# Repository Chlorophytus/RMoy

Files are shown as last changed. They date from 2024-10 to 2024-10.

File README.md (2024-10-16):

# RMoy
Simple 12V 0.5A headphone amplifier convergent with the CMoy's design and philosophy. This is in early alpha stage but will be on Tindie soon.

## Background
Initially named "Seven Wonder", I realized that this converged with the famous CMoy headphone amplifier, freely available. I decided to open source it for others to enjoy.

## Specifications
- Gain is about 8x
- OPA2134 opamp (in the process of testing other opamps out there but this seems to be most happy)
- Nichicon UKA capacitors in the signal path (needed for coupling)
- The same magenta LED used in the BD139 Thing

## Caveats
- No knob like the CMoy has, computers and other devices have digital OS volume control. Use those.

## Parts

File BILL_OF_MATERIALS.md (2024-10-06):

# Bill of Materials

You should populate U1 with a Burr Brown/Texas Instruments OPA2134PA.

It is recommended to use a 12V 500mA center-positive power adapter.

## Capacitors

- `C1`/`C2`: Nichicon UKA1H101MPD - 100µF op-amp input coupling
- `C3`/`C4`: Murata RDE5C1H102J0K1H03B - 1nF op-amp pole splitting
- `C5`/`C6`: Nichicon UKA1V221MPD - 220µF op-amp output coupling
- `C7`: Chemi-Con EKZN250ELL471MJC5S - 470µF power coupling
- `C8`: Murata RDE5C1H104J2K1H03B - 100nF power coupling

## Resistors

- `R1`/`R2` - YAGEO MFR-25FBF52-270R - path for audio input to ground
- `R3`/`R4` - YAGEO MFR-25FBF52-100R - path for feedback to ground
- `R5`/`R6` - YAGEO MFR-25FBF52-680R - path for feedback to U1
- `R7` - YAGEO MFR-25FBF52-4K7 - LED current limiting resistor

## Miscellaneous Components

- `J1`/`J2` - Same Sky SJ1-3535 - stereo headphones in/out jacks
- `J3` - Same Sky PJ-102AH - DC power jack
- `U1` - TE Connectivity 2485264-1 - 8-DIP socket for op-amp
- `D1` - Kingbright WP7113VRVC1C - LED power indicator

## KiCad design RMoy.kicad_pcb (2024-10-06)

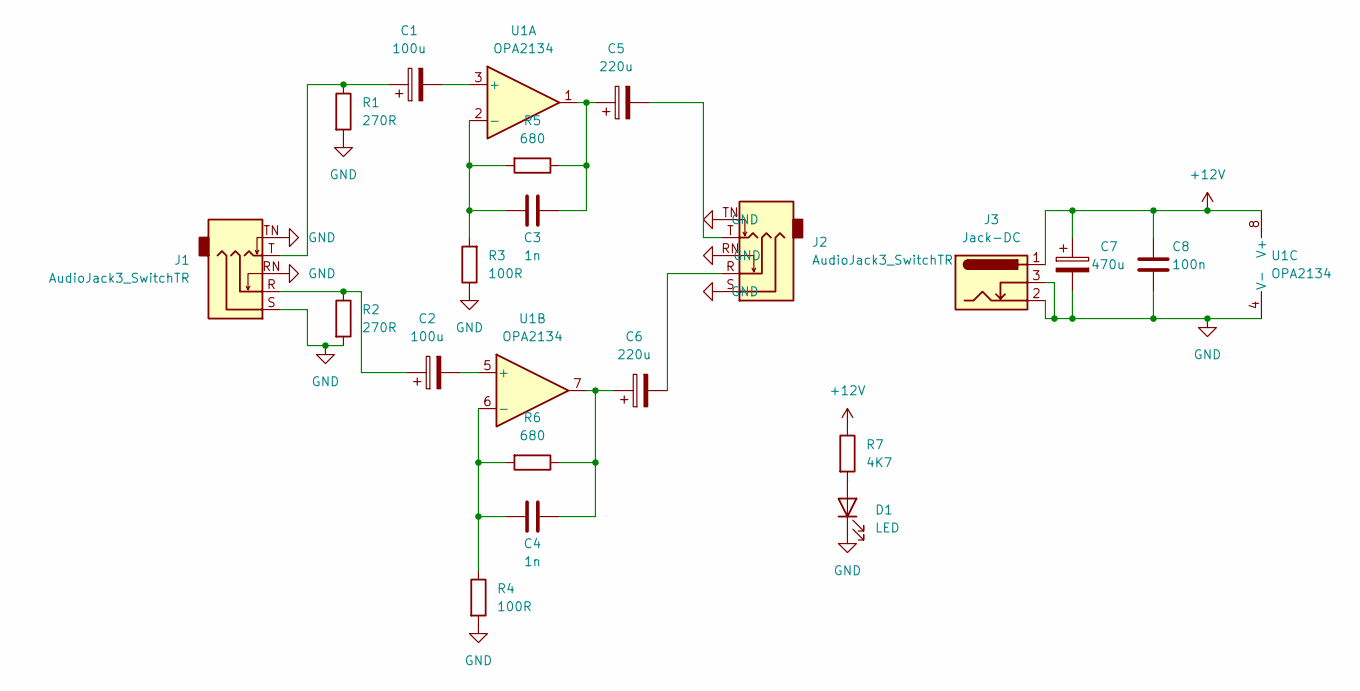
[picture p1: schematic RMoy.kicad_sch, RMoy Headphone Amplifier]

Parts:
C1, C2: 100u; CP_Radial_D8.0mm_P3.50mm
C3, C4: 1n; C_Disc_D5.0mm_W2.5mm_P5.00mm
C5, C6: 220u; CP_Radial_D8.0mm_P3.50mm
C7: 470u; CP_Radial_D10.0mm_P5.00mm
C8: 100n; C_Disc_D5.0mm_W2.5mm_P5.00mm
D1: LED; LED_D5.0mm
J1, J2: AudioJack3_SwitchTR; Jack_3.5mm_CUI_SJ1-3535NG_Horizontal_CircularHoles
J3: Jack-DC; BarrelJack_CUI_PJ-102AH_Horizontal
R1, R2: 270R; R_Axial_DIN0207_L6.3mm_D2.5mm_P10.16mm_Horizontal
R3, R4: 100R; R_Axial_DIN0207_L6.3mm_D2.5mm_P10.16mm_Horizontal
R5, R6: 680; R_Axial_DIN0207_L6.3mm_D2.5mm_P10.16mm_Horizontal
R7: 4K7; R_Axial_DIN0207_L6.3mm_D2.5mm_P10.16mm_Horizontal
U1: OPA2134; DIP-8_W7.62mm_Socket

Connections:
+12V: C7.1, C8.2, J3.1, R7.1, U1.8 (V+)
GND: C7.2, C8.1, D1.1 (K), J1.RN, J1.S, J1.TN, J2.RN, J2.S, J2.TN, J3.2, J3.3, R1.2, R2.2, R3.1, R4.2, U1.4 (V-)
unnamed: C1.1, J1.T, R1.1
unnamed: C2.1, J1.R, R2.1
unnamed: C3.2, C5.1, R5.1, U1.1
unnamed: C4.2, C6.1, R6.1, U1.7
unnamed: C5.2, J2.T
unnamed: C6.2, J2.R
unnamed: D1.2 (A), R7.2
unnamed: C1.2, U1.3 (+)
unnamed: C3.1, R3.2, R5.2, U1.2 (-)
unnamed: C2.2, U1.5 (+)
unnamed: C4.1, R4.1, R6.2, U1.6 (-)

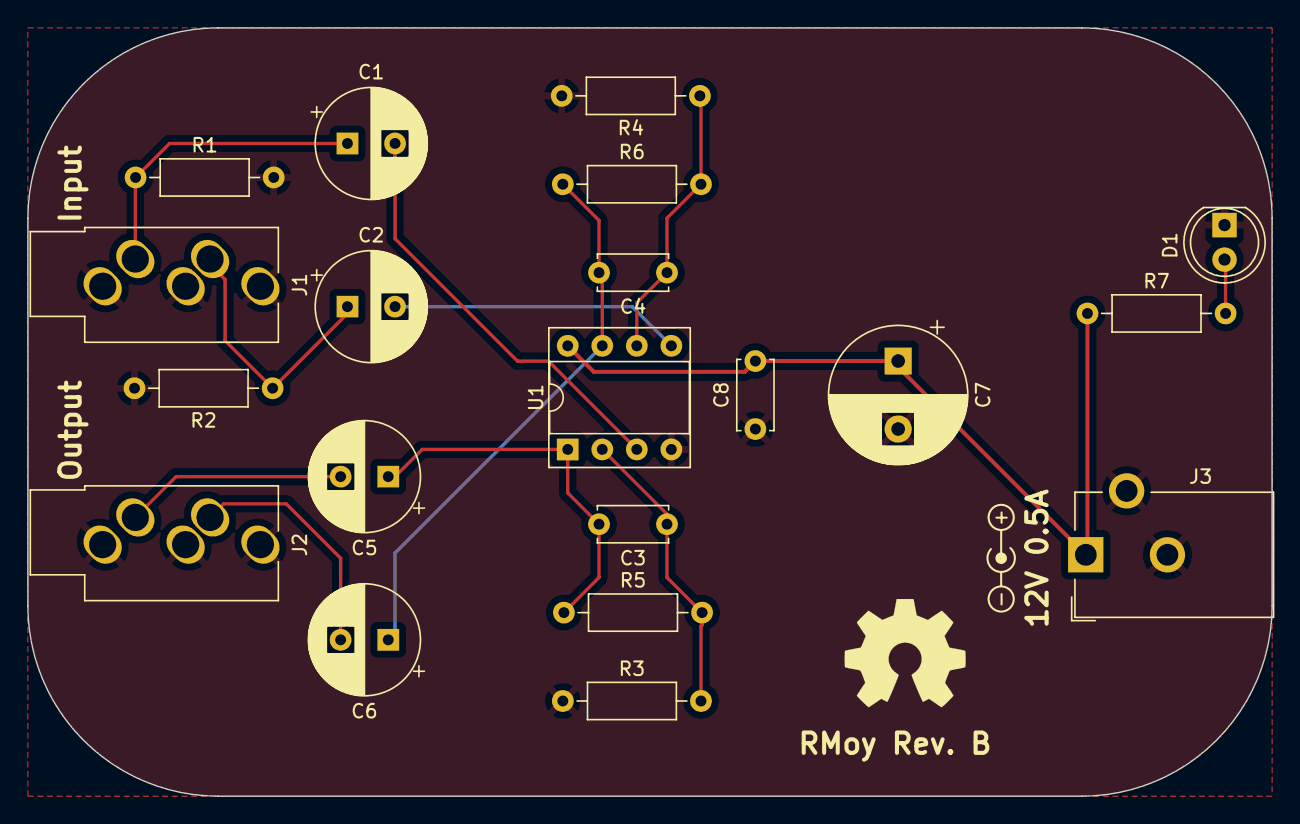
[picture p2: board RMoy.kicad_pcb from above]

Board: 2 copper layers, 91.5 x 56.5 mm, 20 parts (0 on the bottom side), 13 nets.

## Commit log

2022-01-12 Add RMoy Rev.A files
    [RMoy.kicad_pcb, RMoy.kicad_sch]
2024-10-05 add revised parts list
    TODO: C1/C2/C5/C6 have not been modified, are they obsolete?
    [RMoy.kicad_sch]
2024-10-05 C1/C2 are now 100µF non-EOL parts
    [RMoy.kicad_sch]
2024-10-05 PCB is reworked
    [RMoy.kicad_pcb, RMoy.kicad_sch]
2024-10-06 update BOM to add actual resistor SKUs
2024-10-06 rev.B try
    [RMoy.kicad_pcb]
